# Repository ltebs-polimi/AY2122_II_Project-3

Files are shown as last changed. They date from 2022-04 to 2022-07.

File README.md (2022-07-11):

# Electronic Technologies and Biosensors Lab - Project 3
# Academic Year 2021/2022 - II Semester

## Smart tennis racket able to monitor and classify technical tennis movements

**GOAL**

Classification of the three main tennis shots (forehand, backhand and serve) using a tennis racket equipped with an IMU sensor.

**PROJECT SPECIFICATIONS** 

To pursue this goal we had to: 

*	Acquire and process raw accelerometer and gyroscope data from an IMU sensor.
*   Use a Bluetooth module for real-time communication between the microcontroller and the PC to make the device pluggable on a real racket.
*   Program a classification algorithm for gesture recognition.
*	Provide the end player with a Graphical User Interface to visualize in real-time the type of shots predicted during the match. 
*	Print the custom PCB to reduce instrumentation bulkiness. 
*	Design a 3D printed case that includes the microcontroller and the whole instrumentation. 

**CLINICAL NEEDS**

This project addresses the following clinical needs: 

* Sport performance &#x2192; Recognizing and taking memory of shots is a feature that could simplify the work of tennis trainers, that still take notes manually, to understand if the athletes are developing some fundamentals at expenses of the others. 
In the future, associating the information about the type of shot with the corresponding number of points scored by the player can be useful to understand which are the strengths and the weaknesses of the player and therefore to better target the training. 

* Prevention &#x2192; Epicondylitis is an inflammation of the wrist extensor muscles, at their point of insertion.
It is a consequence of repeated microtraumas over time, typical of those who play tennis.
Some experts state that from 10% to 50% of cases this pathology is due to an incorrect technique of execution of the backhand. 
Therefore, the number of backhand shots made by the tennis player could be a useful information for this purpose.

**HARDWARE** 

On the custom PCB are plugged the following components: 

* PSoC microcontroller &#x2192; 3.3V - 5V of power supply
* 9V battery
* Voltage regulator LM7805 (9V to 5V)
* MPU9250 9-axis IMU sensor &#x2192; 5V of power supply
* Bluetooth module HC-06 &#x2192; 3.3V - 5V power supply 

**DEVICE DESIGN** 

Two 3D printed components, fixed together: 

* Housing of the PCB to be interlocked to the handle of the tennis racket.
* Cap of the case.

**PROBLEMS ENCOUNTERED** 

* The FIFO buffer was not used: the datasheet of the MPU9250 was cryptic, and the implementation very difficult and time consuming. So, we decided to read the data from the IMU continuously by using an interrupt. 

* We could not use the switch button: the problem was in the interrupt used to read the data, that did not allow the button to change its state. We partially fixed this problem by adding a button on the GUI. 

* We could not use the LED on the PCB: the problem was with the PCB trace that linked the LED with the ground plane. We partially solved this problem by adding a LED on the GUI. 

**FUTURE DEVELOPMENTS**

The system we have obtained up to now can be further improved by:
* Combining the intertial measurements with dynamic force sensor measurements (FSR), so as to fully characterize the tennis stroke.
* Calculate meaningful parameters from accelerations through more in-depth data post-processing, useful for biomechanical analysis.
* Visualization of the obtained data plots on the GUI.

-----------------

**Organization of the Github repository**

* *3DPrinting_PCB* &#x2192; design of the 3D prints with Fusion 360
* *Acquisitions* &#x2192; CSV files and Python code to train the classifier
* *Biblio* &#x2192; literature
* *Datasheets* &#x2192; HW components' datasheets
* *PCB* &#x2192; design of the custom PCB with Eagle
* *PSOC_firmware* &#x2192; C code to program PSOC microcontroller and HW components 
* *Python_serial* &#x2192; Python code to acquire, decode, classify and display data on the implemented GUI

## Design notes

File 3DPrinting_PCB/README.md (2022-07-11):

## Electronic Technologies and Biosensors Lab - Project 3
## Academic Year 2021/2022 - II Semester

# CASE DESIGN with FUSION360 

**PREREQUISITES**

The ideal case should be:
-  positioned in a spot on the racket that could not be hit by ball strikes during the game session;
- the least bulky as possible.

To pursue these goals, we thought of print 2 components:
1. a main body for PCB housing &#x2192; to be attached to the handle of the racket, with a geometry compatible with the size of the PCB;
2. an end cap &#x2192; that would allow to open the case to possibly change PCB and its components. 

The main body presents also two holes, one for a switch button to use to activate the device, one for an LED to signal that the device is running. However, these 2 components were not used in the final device. 

We used the Fusion360 to create the design, by following the steps reported below. 

----------------------------------------

**STEPS**

1. MAIN BODY FOR PCB HOUSING

- Create the sketch consisting of a rectangle with sides 50 mm x 60 mm.
- Extrude the sketch from two sides, one to create a hollow parallelepiped of 40 mm height and 3 mm thickness that would fit perfectly to the racket handle, the other to create a parallelepiped of 100 mm height and 2 mm wall thickness that would contain the PCB. 
- Create the 1 mm thick guides on the two side faces of the parallelepiped, starting with 3.6 mm of the middle of the side face. The guides are used to hold the PCB in place.
- Create two holes 0.8 mm and 0.5 mm in diameter at 50 mm and 60 mm from the base for the led and button, respectively.  

2. END CAP

- Divide the body intended to hold the PCB through a dividing plane, at the height of 20 mm from the bottom, thus obtaining two bodies, one upper and one lower.
- Create an intermediate plane between the two outer faces of the upper body.
- Create a sketch on the plane just found.
- Project the whole lower body onto the sketch.
- Establish an interlocking tolerance of 0.5 mm.
- Draw the interlock, by projecting the height of the toggle equal to 7mm.
- Create an extrusion profile of symmetrical type, width equal to 5 mm.
- Create the sketch on the face where the interlock is to be created.
- Project the interlock onto the wall to create the seat of the interlock.
- Set a tolerance offset for the interlock.
- Extrude along the full length of the body thus creating the interlock seat.

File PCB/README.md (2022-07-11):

## Electronic Technologies and Biosensors Lab - Project 3
## Academic Year 2021/2022 - II Semester

# PCB DESIGN with EAGLE 

To develop the PCB with EAGLE, instead of using the symbols and footprints of the various components, we used the Connectors from the *Sparkfun* library.
In this way we used all the available space and we developed a more compact PCB.

We used:
- For the PSOC &#x2192; 22 connectors, carefully spaced in order to follow the component dimensions.
- For the IMU &#x2192; 6 connectors, carefully spaced in order to follow the component dimensions.
- For the HC-06 Bluetooth module &#x2192; 4 connectors in order to follow the component dimensions.
- For the voltage regulator &#x2192; 3 connectors.
- For the battery &#x2192; 2 connectors.
- For the LED and for the button (not used later on) &#x2192; 2 connectors. 
- For the 330&#8486; LED resistance (not used later on) &#x2192; component symbol and footprint.  

After developing the PCB with the standard procedure we soldered the female headers on it and we added the components.

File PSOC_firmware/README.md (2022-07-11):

## Electronic Technologies and Biosensors Lab - Project 3
## Academic Year 2021/2022 - II Semester

# PSoC CODE

This code allows to use a MPU9250 9-axis IMU sensor with a PSoC microcontroller to acquire and transmit accelerometer and gyroscope data using a Bluetooth module. 	

*AnnotationLibrary_lib* is necessary to use the components' APIs and run the code.

--------------------------------------------

**DEFAULT IMU SETTINGS**

- Accelerometer and gyroscope data from the IMU are read when the "Data Ready" internal interrupt is triggered, reporting that "New data is available to be read from Sensors Registers".

- The sample rate is set to 200 Hz by scaling the internal sample rate equal to 1kHz with a sample rate divider equal to 4: SMPLRT = INT_SMPLRT / (1 + SMPLRT_DIV)

- The accelerometer data is expressed in &#177;2 g while the gyroscope data is expressed in &#177;250 dps (degrees per second).

In the *MPU9250.c* file are present all the functions to handle the IMU registers and the FIFO buffer (not used at the end).
The function used to opportunely set the IMU registers in order to follow these settings is *MPU9250_Start()*.

**CODE**

In MPU9250, for each axis of each measurement there are 2 registers containing high and low bytes, for a total of 12 bytes.

We set up the reading settings as follows:

* 1 frame (*data*) containing &#x2192; 12 bytes: contents of the registers related to accelerometer and gyroscope measurements.

* 1 packet (*packet_to_send*) containing &#x2192; (*N_FRAME* * 12 + 2 ) bytes: 
    -	1 HEADER = 0XA0
    -	*N_FRAME* * 12 
    -	1 TAIL = 0XC0

After reading *N_FRAME*, the packet is sent to the PC via HC-06 Bluetooth module (baud rate = 57600 bps).

We set *N_FRAME* = 10, thus creating packets made of 122 bytes.

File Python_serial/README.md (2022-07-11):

## Electronic Technologies and Biosensors Lab - Project 3
## Academic Year 2021/2022 - II Semester

# PYTHON code 

This code allows to:
1.  Collect via Bluetooth the raw data from an MPU9250 9-axis IMU sensor mounted on a smart tennis racket;
2.	Classify the tennis shot made according to the accelerometer & gyroscope measurements obtained;
3.	Display on a GUI the type of shot predicted in real-time.

> IMPORTANT:
* *BT_COM* needs to be specified according to your PC settings.
* *training_dataset.csv* file must be present in the same folder as this code.

--------------------------------------------

**GUI WINDOW & WIDGETS**

In order to create the GUI we have used *Tkinter Python Library* and to make it communicate with the Classification Algorithm we used *Threading Python Library*. 

The GUI contains the following widgets: 

* Timer, which keeps track of the time of the acquisition session.

* LED, which turns green or red depending on the acquisition phase.

* Scoreboard, containing the scores related to the different shots predicted by the Classification Algorithm: *serve*, *forehand* and *backhand*.

* Buttons: 
    * COM &#x2192; to open the serial port (COM) and build the Random Forest Classifier.
    * START &#x2192; to enable the Timer and to activate the 2 threads: *Start_GUI()* and *Start_acquisition()*.
    * STOP &#x2192; to disable the Timer and to block the acquisitions, thus showing the number of shots made up to that moment.
    * RESET &#x2192; to reset Timer and Scoreboard in order to prepare them for another session (to be used after pushing the STOP button).

--------------------------------------------

**DATA COLLECTION**

Once the COM button is pressed, the *BT_COM* port of the Bluetooth module HC-06 is open at baudrate = 57600 bps.
When the START button is pressed, the 2° thread (*Start_acquisition()*) calls the function *Predict_Data_Packet()* which allows to acquire and classify the data from the IMU. 

Each acquisition is done by reading *N_PACKETS* and decoding the corresponding array of data (*data*).
With *N_PACKETS* = 40, the acquisition takes about 4 seconds, which is approximatively equal to the duration of one tennis shot during a match.

Each packet contains 122 bytes: 
-	1 HEADER = 0XA0
-	120 bytes, representing 10 frames of data: each frame contains 12 bytes corresponding to accelerometer and gyroscope data registers, with 2 bytes (high and low bits) for each ACCX, ACCY, ACCZ, GYRX, GYRY, GYRZ reading.
-	1 TAIL = 0XC0

Data decoding is done by creating a *mat_big* matrix with:
-	400 rows &#x2192; *N_FRAME* * *N_PACKETS* = 10*40 
-	6 columns &#x2192; raw data: ACCX, ACCY, ACCZ, GYRX, GYRY, GYRZ (obtained by merging high bytes & low bytes for each measurement and converting the acceleration and gyroscope values to the right FSR (&#177;2g, &#177;250 dps)).

This matrix is then given to the Classification Algorithm that, about every 4 seconds, predicts the type of shot.

--------------------------------------------

**RANDOM FOREST CLASSIFIER**

TRAINING

The *Classifier_Training()* function is run just once when the COM button is pressed. 
The Random Forest Classifier has been trained with 140 acquisitions (*training_dataset.csv*). 
One acquisition is given by the 1°, 2° and 3° quantiles values of the 6 IMU measurements.

For more details about acquistions and choice of the classifier see the *acquisition_protocol.pdf* file in the *Acquisitions* folder.

MAKING PREDICTIONS

In the *Predict_Data_Packet()* function, from the *mat_big* matrix (representing one acquisition), 1° (0.25), 2° (0.5 = median) and 3° (0.75) quantiles of each IMU measurement are extracted and used to guess the shot made with the Random Forest classifier. 
The label *shot* returned by the Classification Algorithm is then used to update the shots' counts in the Scoreboard: 
- shot = 0 &#x2192; Forehand
- shot = 1 &#x2192; Backhand
- shot = 2 &#x2192; Serve
- shot = 3 &#x2192; "no shot"

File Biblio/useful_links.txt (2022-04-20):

https://www.ubitennis.net/2021/01/tennis-in-the-future-an-overview-of-wearables-and-sensors/

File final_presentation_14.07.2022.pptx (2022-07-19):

## SMART TENNIS RACKET FOR TRAINING MONITORING

Electronic Technologies and Biosensors Laboratory
A.A 2021/2022 - presentation 14/07/2022
Politecnico di Milano

Project 3

Tutor: Matteo Rossi
Professor: Pietro Cerveri

Natalia Ginghini
Letizia Mozzorecchia
Aurora Pierantozzi
Adelaide Stucchi

## Goal

Classification of three of the fundamental
tennis shots - forehand, backhand, serve -
by equipping a tennis racket with an
IMU sensor.

## Needs addressed

Sport
Automatic evaluation of athletes’ performances, to understand strenghts and weakenesses, thus better targeting the training.

Clinical
Prevention for Epicondylitis:
10% to 50% of tennis players[1] are at
risk of tennis elbow, mainly due to an
incorrect execution of the backhand.

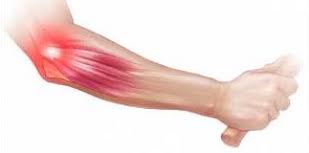
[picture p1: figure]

[1] source: T.K. Robinson PT, DSc, OCS, in Orthopaedic Physical Therapy Secrets (III Edition) (https://www.sciencedirect.com/book/9780323286831/orthopaedic-physical-therapy-secrets), 2017

## Project Specifications

BT COMMUNICATION
PSoC Programmer
between the PSoC and the PC to make the device pluggable on a real racket.

to visualize in real-time the type of shots predicted during the match.
GUI
Python: Tkinter, Threading

3D CASE PRINT
Eagle, Fusion360
to be attached to the racket, in a way that does not interfer during the match.

for real-time gesture recognition of the three
tennis shots.
CLASSIFICATION ALGORITHM
Python: Scikit-learn

1

2

4

3

## Firmware: MPU-9250 settings

Sample rate = 1k Hz / (1 + 4) = 200 Hz

Full scale range
- Accelerometer → ±2 g
- Gyroscope → ±250 dps

Interrupt
Accelerometer & gyroscope registers read when the "Raw Data Ready" internal interrupt is triggered.

## Firmware: Data collection

Registers raw
data reading

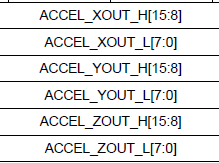
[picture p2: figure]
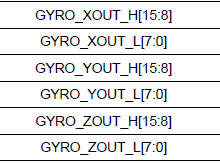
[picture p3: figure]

1 frame
12 bytes

Data
encoding

header
= 0xA0

10 frames
10*12 bytes

tail
= 0xC0

Data
decoding

40 packets

matrix (400,6)
400 rows → N frames * N packets
6 columns → IMU measurements

1 packet
(10*12 + 2) bytes

## PCB: HW components

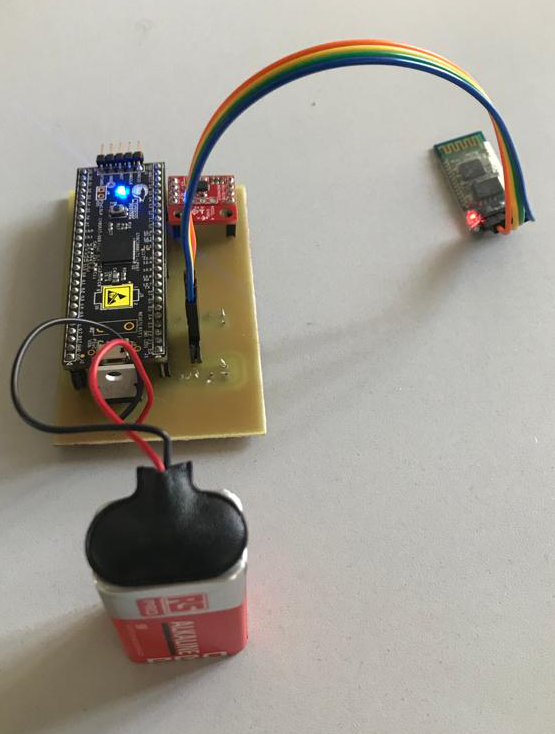
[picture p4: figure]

PSoC 5 microcontroller
5V

Battery
9V

Voltage regulator
9V - 5V

MPU-9250 9-axis IMU
5V

Bluetooth HC-06 module
5V

## Case design: features

Ideal characteristics
- Light & thin
- As small as possible
- Stable during the match
- Protected from the strokes
Location
The case is attached at the bottom of the racket,
so that it does not get hit by the ball during the game.

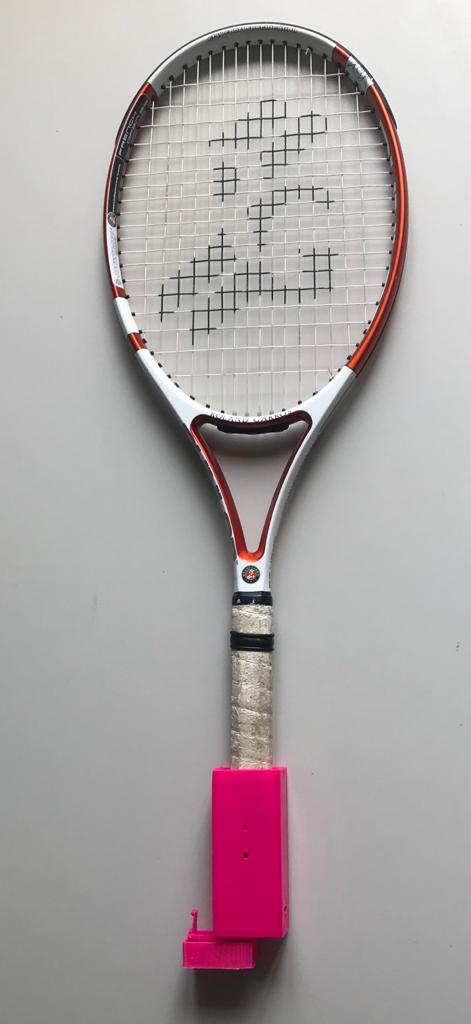
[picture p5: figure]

## Case design: 3D project

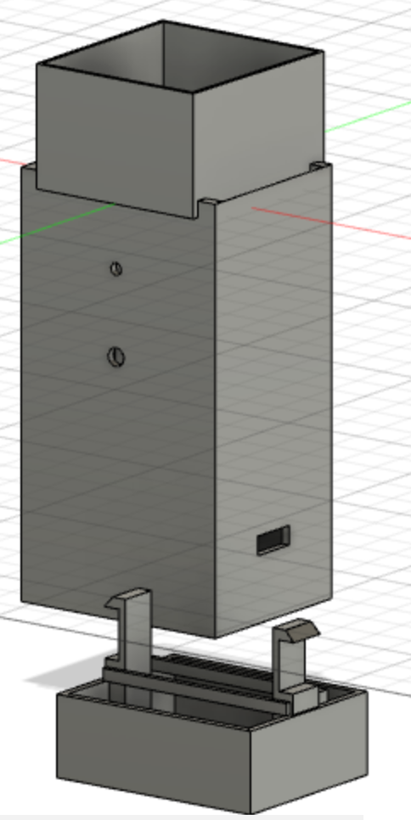
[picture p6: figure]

Attachment to the racket handle

Holes: for led and switch button [2]

BODY 1: PCB HOUSING

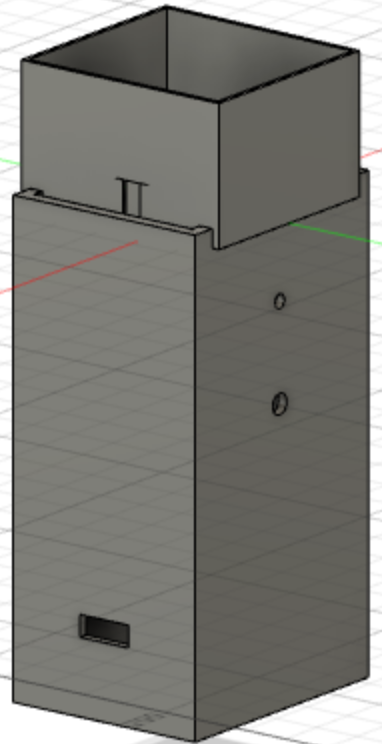
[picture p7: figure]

PCB insertion

Cover, useful if we want to change the PCB or to replace the battery, stabilized through a tape

BODY 2: END CAP

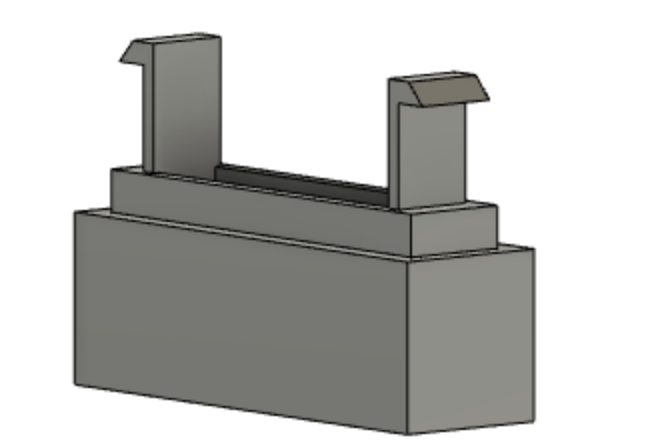
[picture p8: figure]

[2] not present in the final device

## Acquisition protocol

- Right-handed players only.
- Position of the PCB within the case for acquisitions as shown in the picture.
- Total number of subjects → 4
- Duration of each acquisition → 4 sec
- Gestures acquired and related labels:
  - Forehand → label = 0
  - Backhand → label = 1
  - Serve → label = 2
  - No-shot → label = 3

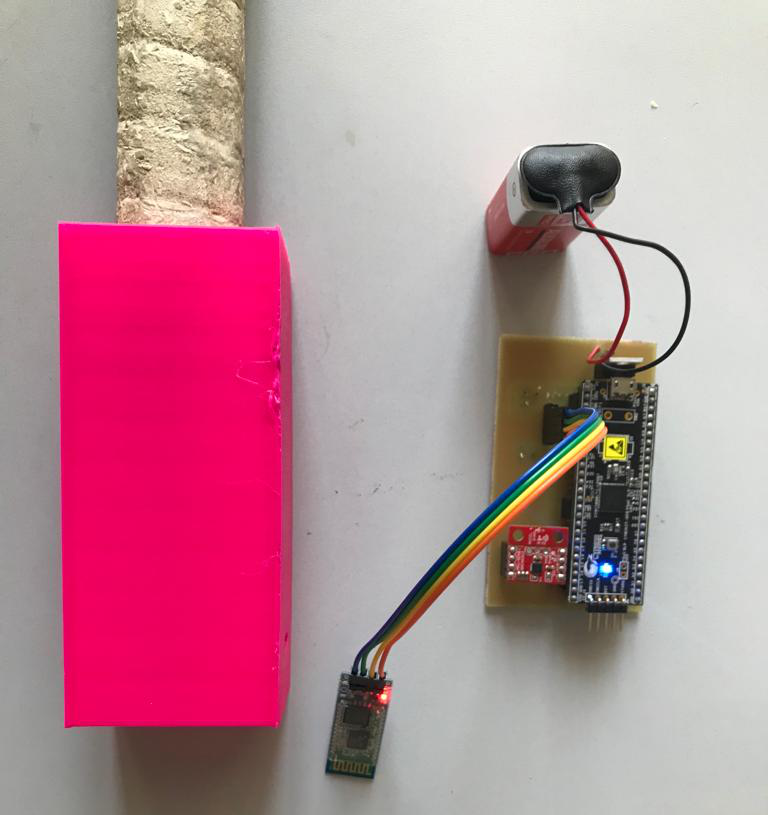
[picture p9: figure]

## Classification

FEATURES ENGINEERING

TRAINING DATASET

TRAINING DATASET

SPLITTING DATASET

SPLITTING DATASET

MULTICLASS CLASSIFIERS

MULTICLASS CLASSIFIERS

- 1 target variable: type of shot → ‘label’.
- 18 explanatory variables: gyroscope and accelerometer quantiles.
- Training: 70% of the entire dataset.
- Test: 30% of the entire dataset.

4 x
4 x
4 x
1 x

forehand: 0
backhand: 1
serve: 2
no shot: 3

x 10
x 10
x 10
x 20

140 acquisition files

training_dataset → (140,19)

Explanatory variables:
- Before
  - IMU measurements: ACCX, ACCY, ACCZ, GYRX, GYRY, GYRZ
  - 1 acquisition file → (400,7)
- After
  - 1° (0.25), 2° (median), 3° (0.75) quantiles of each IMU measurement: ACCX_25, ACCX_50, ACCX_75, … , GYRZ_25, GYRZ_50, GYRZ_75
  - 1 acquisition file → (1,19)

Trained classifiers:
Decision Tree, Logistic Regression, K-Nearest Neighbors, Support Vector Machine, Random Forest.

## Classification algorithm: results

Decision Tree | f1 (train) | f1 (test)
| 0.847222 | 0.857143
| Confusion matrix

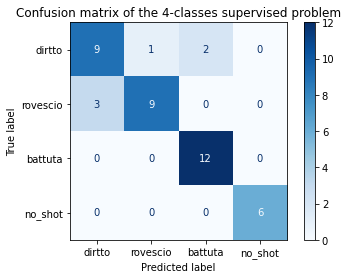
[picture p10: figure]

Log Reg | f1 (train) | f1 (test)
| 0.806818 | 0.809523
| Confusion matrix

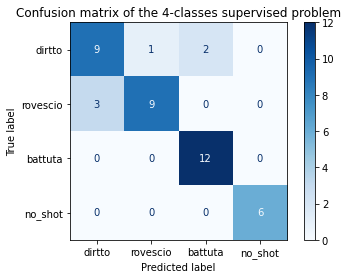
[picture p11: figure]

## Classification algorithm: results

KNN | f1 (train) | f1 (test)
| 0.704861 | 0.761905
| Confusion matrix

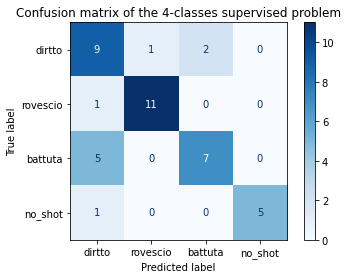
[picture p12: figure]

SVM | f1 (train) | f1 (test)
| 0.938447 | 0.833333
| Confusion matrix

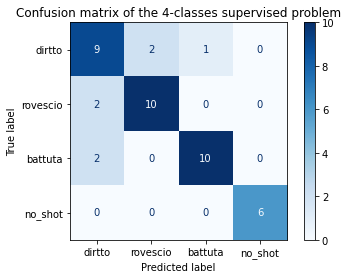
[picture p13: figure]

## Classification algorithm: results

The best classifier is
Random Forest
✔ High F1 score for both training and
test sets.
✔ Similar F1 scores for training test and test set → no overfitting.
✔ Interpretability.

Random Forest | f1 (train) | f1 (test)
| 0.949179 | 0.904761
| Confusion matrix

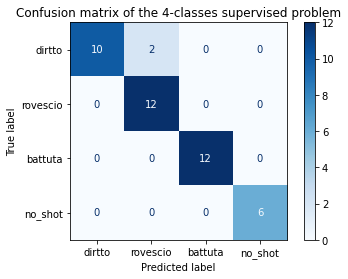
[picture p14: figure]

## GUI

COM
Open the serial port and build the Classifier.

START
Enable Timer and
start the threads.

STOP
Disable Timer and
block acquisitions.

RESET
Prepare Timer and
Scoreboard for the
next session.

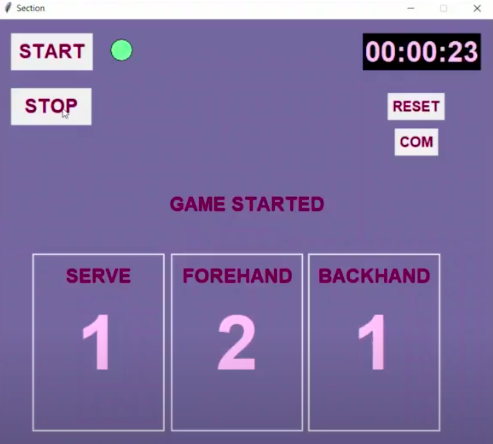
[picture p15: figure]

## Applications of our smart racket

Automatic, real-time classification of 3 tennis shots.

Evaluation and consequent improvement of the athlete’s style of play.

Identification of possible associations between the prevalence of a type of shot with joint pain.

## Problems encountered

- FIFO buffer → not used due to the cryptic MPU-9250 datasheet which made the FIFO implementation difficult and time consuming. We decided, then, to read the data from the IMU continuously by using another internal interrupt (‘Raw Data Ready’).
- Switch button → not used due to the interrupt used to read data registers, that did not allow to read the button state. We partially fixed this problem by adding a button on the GUI.
- LED → not used due to a problem with the PCB trace that linked the LED with the ground plane. We partially solved this problem by adding a LED on the GUI.

## Future developments

- Calculate meaningful parameters from accelerations through more in-depth data post-processing, useful for biomechanical analysis.
- Combining the inertial measurements with dynamic force sensor measurements (e.g. FSR), so as to fully characterize the tennis shot.
- Visualization of the obtained data plots on the GUI.
- Have a larger acquisition dataset in order to obtain more accurate classifications.
- Make the device suitable for left-handers.

## Virtual Demo

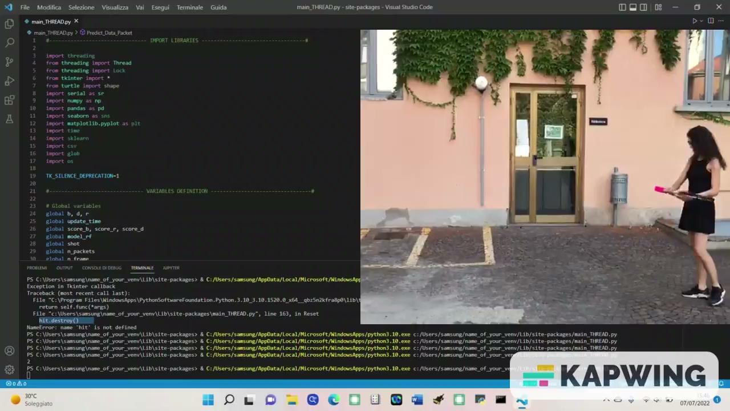
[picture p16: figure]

Thanks for your attention.

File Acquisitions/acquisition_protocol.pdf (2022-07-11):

Electronic Technologies and Biosensors Lab – Project 3 Academic Year 2021/2022 – II Semester

### ACQUISITION PROTOCOL

code used for this purpose: acquisitions_training_classifier.ipynb

Prerequisites

- Right-handed players only.
- Position of the PCB within the case for acquisitions as shown in the picture below (IMU facing the game net in the forehand grip).

Training phase

Number of subjects: 4

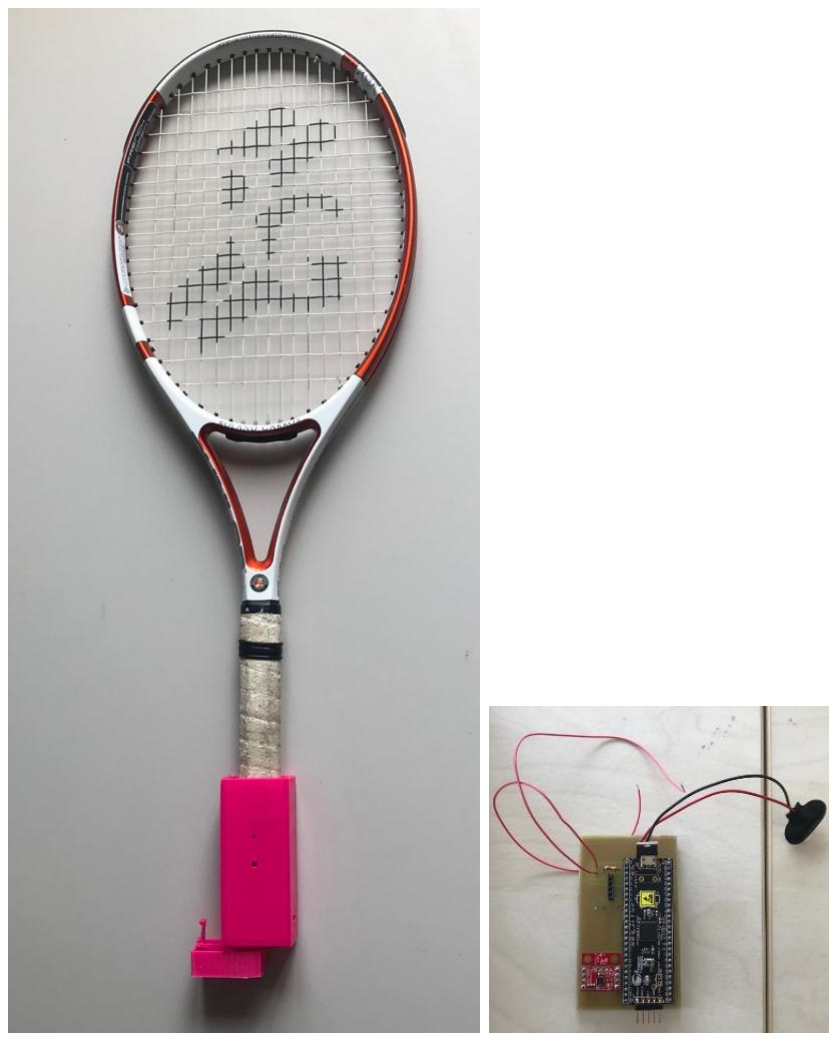
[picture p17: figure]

Duration of each acquisition: about 5 seconds

Gestures acquired and related labels set:

- Forehand : ‘0’
- Backhand: ‘1’
- Serve: ‘2’
- No shot: ‘3’

Number of acquisitions for each shot (‘forehand’, ‘backhand’, ‘serve’) → 10 for each subject. Number of acquisitions for the ‘no shot’ gesture → 20 acquisitions for 1 subject only. Number of acquisition files → 140 (in the “acquisitions_for_TRAINING” folder of the GitHub repository)

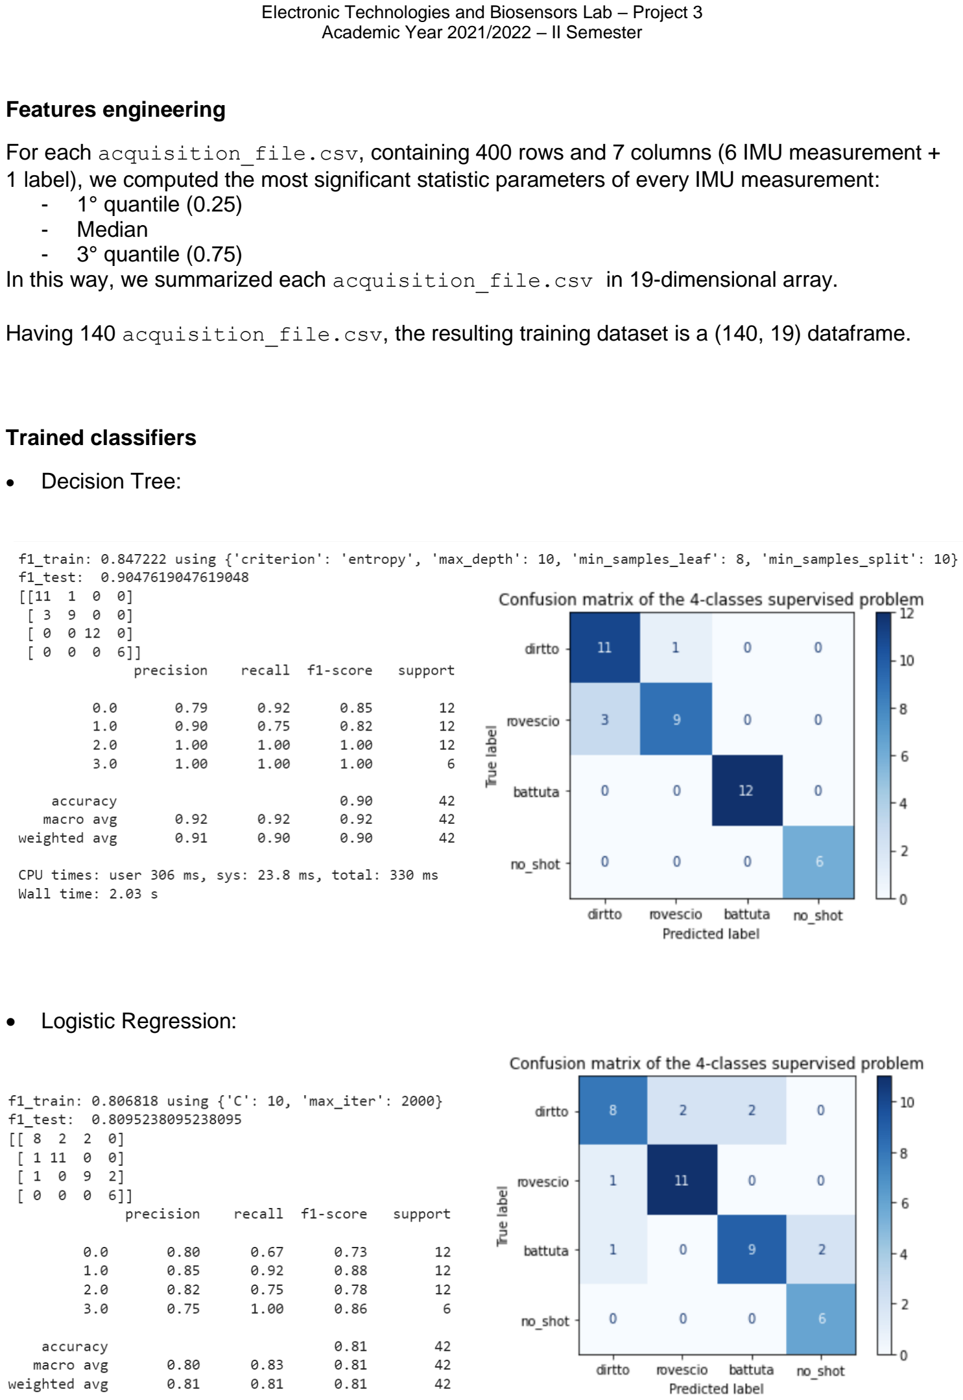
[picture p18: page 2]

Features engineering

For each acquisition_file.csv, containing 400 rows and 7 columns (6 IMU measurement + 1 label), we computed the most significant statistic parameters of every IMU measurement:
- 1° quantile (0.25)
- Median
- 3° quantile (0.75)
In this way, we summarized each acquisition_file.csv in 19-dimensional array.

Having 140 acquisition_file.csv, the resulting training dataset is a (140, 19) dataframe.

Trained classifiers

- Decision Tree:
- Logistic Regression:

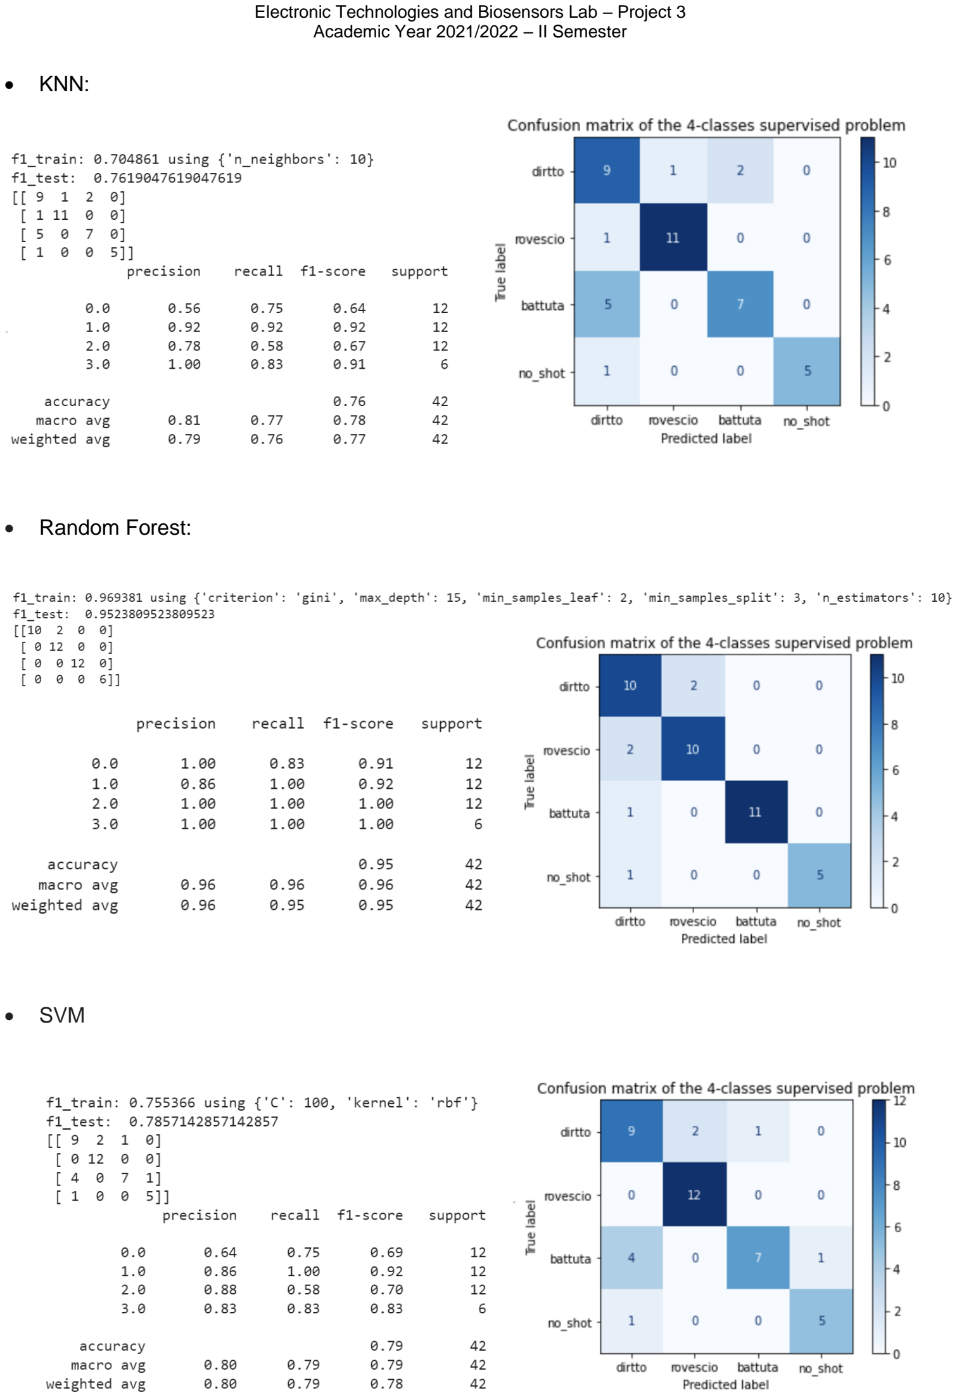
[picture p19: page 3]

- KNN:
- Random Forest:
- SVM

Scaling the data did not lead to significant improvement in the performance of the classifiers, despite improving over fitting in Logistic Regression and KNN; thus, we decided to use the unscaled dataset.

Among the classifiers, we chose Random Forest because of:

✔ High F1 score for both training set and test set.
✔ Similar F1 scores for training sets and test sets, meaning no overfitting problems. ✔ Interpretability of the classifier.

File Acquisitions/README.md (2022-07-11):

## Electronic Technologies and Biosensors Lab - Project 3
## Academic Year 2021/2022 - II Semester

# CLASSIFICATION ALGORITHM FOR GESTURE RECOGNITION

To train and build the classification algorithm able to discriminate the tennis shots by means of accelerometer and gyroscope data, we performed several acquisitions and compared different classifiers.

**ACQUISITION PROTOCOL**

Tennis movements acquired during each acquisition and related labels set: 

- FOREHAND : '0'
- BACKHAND : '1'
- SERVE : '2'
- NO-SHOT : '3'

The acquisitions have been made by following these settings:

* Duration of each acquisition &#x2192; about 4 seconds
* Number of subjects trained &#x2192; 4
* Number of acquisitions for each tennis shot &#x2192; 10 for each subject
* Number of acquisitions ofr the 'no-shot' gesture &#x2192; 20 for 1 subject only
* Number of acquisition files &#x2192; 140 (present in the *acquisitions_for_TRAINING* folder)

**FEATURES ENGINEERING**

For each acquisition CSV file (400,7), we computed: 
- 1° quantile = 0.25
- 2° quantile (median)
- 3° quantile = 0.75

of every IMU measurement, thus summarizing each CSV acquisition file in a 19-dimensional array.

Having 140 acquisition CSV files, the resulting training set is a (140,19) dataframe, converted in the *training_dataset.csv* file.

**TRAINED CLASSIFIERS**

* Decision Tree
* Logistic Regression
* KNN
* Random Forest
* SVM

Among the reported classifiers, we chose Random Forest as it showed the best performances in terms of F1 score, overfitting and interpretability.

> Further details in the *acquisition_protocol.pdf* file.

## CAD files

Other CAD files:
3DPrinting_PCB/CasePCB v2.f3d

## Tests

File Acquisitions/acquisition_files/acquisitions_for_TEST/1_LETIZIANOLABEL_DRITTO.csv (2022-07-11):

ACC_X | ACC_Y | ACC_Z | GYR_X | GYR_Y | GYR_Z
-1.864 | 1.168 | -1.847 | 212.0 | -136.0 | 160.5
-1.864 | 1.168 | -1.847 | 212.0 | -136.0 | 160.5
-1.864 | 1.168 | -1.847 | 212.0 | -136.0 | 160.5
-1.864 | 1.168 | -1.847 | 212.0 | -136.0 | 160.5
-1.864 | 1.168 | -1.847 | 212.0 | -136.0 | 160.5
-1.864 | 1.168 | -1.847 | 212.0 | -136.0 | 160.5
-1.864 | 1.168 | -1.847 | 212.0 | -136.0 | 160.5
-1.864 | 1.168 | -1.847 | 212.0 | -136.0 | 160.5
-1.864 | 1.168 | -1.847 | 212.0 | -136.0 | 160.5
-1.864 | 1.168 | -1.847 | 212.0 | -136.0 | 160.5
-1.864 | 1.168 | -1.847 | 212.0 | -136.0 | 160.5
-1.864 | 1.168 | -1.847 | 212.0 | -136.0 | 160.5
-1.864 | 1.168 | -1.847 | 212.0 | -136.0 | 160.5
-1.864 | 1.168 | -1.847 | 212.0 | -136.0 | 160.5
-1.864 | 1.168 | -1.847 | 212.0 | -136.0 | 160.5
-1.864 | 1.168 | -1.847 | 212.0 | -136.0 | 160.5
-1.864 | 1.168 | -1.847 | 212.0 | -136.0 | 160.5
-1.864 | 1.168 | -1.847 | 212.0 | -136.0 | 160.5
-1.864 | 1.168 | -1.847 | 212.0 | -136.0 | 160.5
-1.864 | 1.168 | -1.847 | 212.0 | -136.0 | 160.5
1.818 | 0.832 | -1.655 | 212.8 | 160.0 | -218.6
1.818 | 0.832 | -1.655 | 212.8 | 160.0 | -218.6
1.818 | 0.832 | -1.655 | 212.8 | 160.0 | -218.6
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

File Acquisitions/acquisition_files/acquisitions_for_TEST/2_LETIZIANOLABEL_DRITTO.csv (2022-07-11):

ACC_X | ACC_Y | ACC_Z | GYR_X | GYR_Y | GYR_Z
1.902 | 1.232 | -1.735 | 167.8 | 244.2 | -230.8
1.902 | 1.232 | -1.735 | 167.8 | 244.2 | -230.8
1.889 | 1.236 | -1.708 | 171.5 | 239.8 | -229.9
1.889 | 1.236 | -1.708 | 171.5 | 239.8 | -229.9
1.889 | 1.236 | -1.708 | 171.5 | 239.8 | -229.9
1.889 | 1.236 | -1.708 | 171.5 | 239.8 | -229.9
1.889 | 1.236 | -1.708 | 171.5 | 239.8 | -229.9
1.889 | 1.236 | -1.708 | 171.5 | 239.8 | -229.9
1.889 | 1.236 | -1.708 | 171.5 | 239.8 | -229.9
1.889 | 1.236 | -1.708 | 171.5 | 239.8 | -229.9
1.902 | 1.232 | -1.735 | 167.8 | 244.2 | -230.8
1.902 | 1.232 | -1.735 | 167.8 | 244.2 | -230.8
1.889 | 1.236 | -1.708 | 171.5 | 239.8 | -229.9
1.889 | 1.236 | -1.708 | 171.5 | 239.8 | -229.9
1.889 | 1.236 | -1.708 | 171.5 | 239.8 | -229.9
1.889 | 1.236 | -1.708 | 171.5 | 239.8 | -229.9
1.889 | 1.236 | -1.708 | 171.5 | 239.8 | -229.9
1.889 | 1.236 | -1.708 | 171.5 | 239.8 | -229.9
1.889 | 1.236 | -1.708 | 171.5 | 239.8 | -229.9
1.889 | 1.236 | -1.708 | 171.5 | 239.8 | -229.9
0.91 | 0.377 | 1.418 | -106.25 | 0.0 | -166.0
0.91 | 0.377 | 1.418 | -106.25 | 0.0 | -166.0
0.91 | 0.377 | 1.418 | -106.25 | 0.0 | -166.0
0.9062 | 0.4238 | 1.426 | -106.5 | 0.0 | -168.5
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

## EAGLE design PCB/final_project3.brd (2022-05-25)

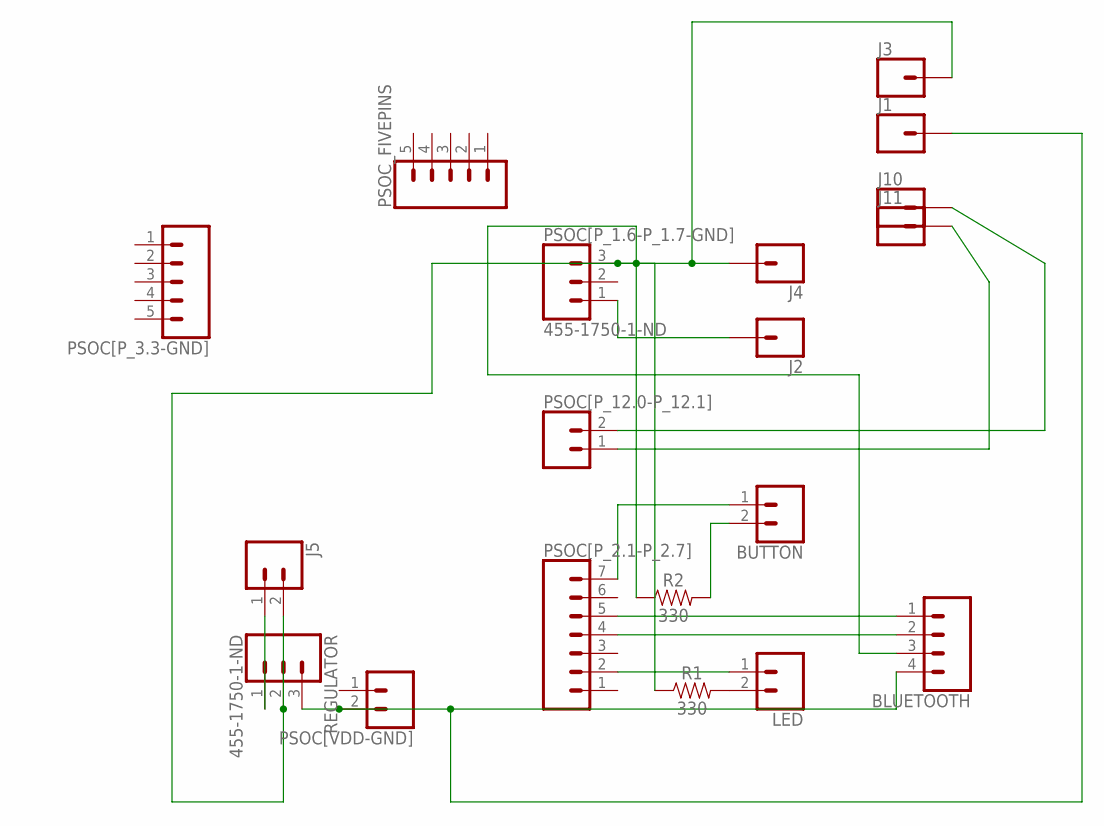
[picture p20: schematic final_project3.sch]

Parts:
BLUETOOTH: CONN_04; 1X04
BUTTON: CONN_02; 1X02
J1, J2, J3, J4, J10, J11: CONN_01; 1X01
J5: CONN_02; 1X02
LED: CONN_02; 1X02
PSOC[P_1.6-P_1.7-GND]: 455-1750-1-ND; 1X03
PSOC[P_2.1-P_2.7]: CONN_07; 1X07
PSOC[P_3.3-GND]: CONN_05; 1X05
PSOC[P_12.0-P_12.1]: CONN_02; 1X02
PSOC[VDD-GND]: CONN_02; 1X02
PSOC_FIVEPINS: CONN_05; 1X05
R1, R2: 330; AXIAL-0.3
REGULATOR: 455-1750-1-ND; 1X03

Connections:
BUTTON: BUTTON.1, PSOC[P_2.1-P_2.7].7
GND3: BLUETOOTH.3, J3.1, J4.1, J5.2, PSOC[P_1.6-P_1.7-GND].3, R1.P$1 (1), R2.P$1 (1), REGULATOR.2
LED: LED.1, PSOC[P_2.1-P_2.7].2
unnamed: J5.1, REGULATOR.1
unnamed: J2.1, PSOC[P_1.6-P_1.7-GND].1
unnamed: J11.1, PSOC[P_12.0-P_12.1].1
unnamed: J10.1, PSOC[P_12.0-P_12.1].2
RX_BT-TX_PSOC: BLUETOOTH.1, PSOC[P_2.1-P_2.7].5
R_BUTTON: BUTTON.2, R2.P$2 (2)
R_LED: LED.2, R1.P$2 (2)
TX_BT-RX_PSOC: BLUETOOTH.2, PSOC[P_2.1-P_2.7].4
VDD: BLUETOOTH.4, J1.1, PSOC[VDD-GND].2, REGULATOR.3

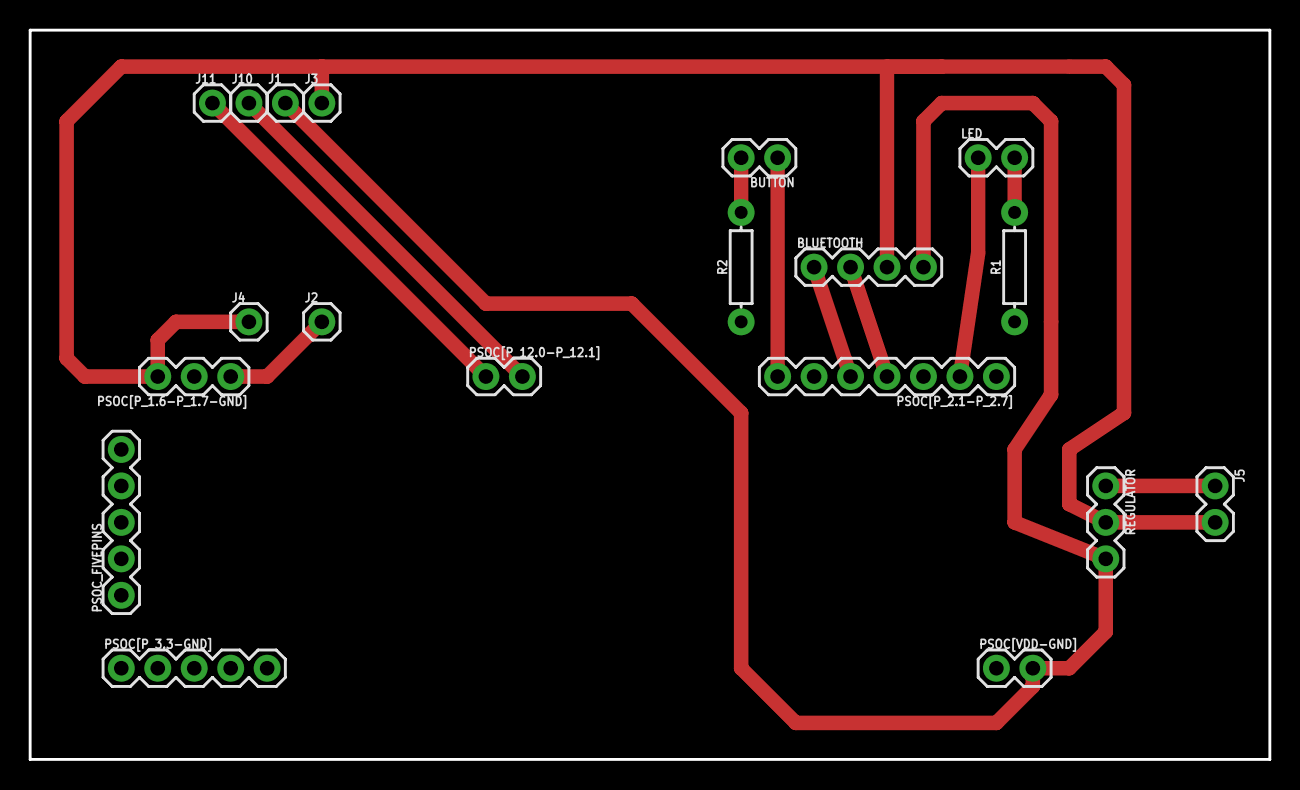
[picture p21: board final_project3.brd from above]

Board: 2 copper layers, 86.4 x 50.8 mm, 19 parts (0 on the bottom side), 12 nets.

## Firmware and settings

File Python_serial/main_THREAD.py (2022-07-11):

#--------------------------------------------- IMPORT LIBRARIES ----------------------------------------------#

import threading 
from threading import Thread
from threading import Lock
from tkinter import *
from turtle import shape
import serial as sr
import numpy as np
import pandas as pd 
import seaborn as sns
import matplotlib.pyplot as plt 
import time
import sklearn
import csv
import glob
import os

TK_SILENCE_DEPRECATION=1

#------------------------------------------ VARIABLES DEFINITION --------------------------------------------#

# Global variables
global b, d, r
global update_time
global score_b, score_r, score_d
global model_rf 
global shot    
global n_packets 
global n_frame 
global send_bytes 
global mat 
global serialPort
global data
global flag_stop
global flag_reset 
global flag_start
global hit


# Variables initialization
hour, minute, second = 0, 0, 0
running = False 
flagb = False 
flagr = False 
flagd = False 
flag_start = False
flag_stop = False
flag_reset = False
BT_COM = "COM19"                                    # Bluethoot HC-06 COM port
n_packets = 40                                      # Number of packets to classify 1 gesture
n_frame = 10                                        # Each packet has n_frame
send_bytes = (12*n_frame)+2                         # Bytes within 1 packet sent by the BT 
mat = np.zeros(shape=(n_frame,6), dtype=np.float16) # Array wtih inside 1 packet of data 




#------------------------------------------ FUNCTIONS DEFINITIONS --------------------------------------------#


##############################################
# Multithreading():
# MULTITHREADING FUNCTION RUNNING IN PARALLEL
#   1. GUI activation
#   2. Data acquisition
##############################################

def Multithreading():
  global t1
  global t2
 
  t1 = Thread(target = Start_GUI)
  t2 = Thread(target = Start_acquisition)
  
  t1.start()
  t2.start()


#############################################################
# Clock():
# FUNCTION ACTIVATING THE CLOCK WHEN START BUTTON IS PRESSED
############################################################# 
  
def Clock():
  global hour, minute, second
  global update_time

  second = second + 1 

  if second == 60:
    minute += 1 
    second = 0 

  if minute == 60:
    hour += 1 
    minute = 0 
            
  string_hour = f'{hour}' if hour > 9 else f'0{hour}'
  string_minute = f'{minute}' if minute > 9 else f'0{minute}'
  string_second = f'{second}' if second > 9 else f'0{second}'
                    
  clock_timer.config(text = string_hour + ":" + string_minute + ":" + string_second)
  update_time = clock_timer.after(1000, Clock)


#############################
# Stop_GUI():
# FUNCTION FREEZING THE GUI
#############################

def Stop_GUI():
  global flag_stop
  global running
  global flagr, flagb, flagd
  global hit
  global b, d, r 

  acquisition.destroy()
  flag_stop = True

  # Stop timer updating
  if running:
    clock_timer.after_cancel(update_time)
    running = False

  # Switch off led
  box_led4 = Canvas(window, bd =0, bg = "#666699", height= 80, width = 80, highlightthickness=0)
  box_led4.grid(row = 20, columns = 7, padx = 135, sticky = "W")
  oval3 = box_led4.create_oval(25,22,55,52, fill = "red")

  # Plot the most frequent hit
  if (b > r and b > d):
    print(b)
    hit = Label(window, text = "The most frequent hit was SERVE", font = ("Orator Std", 15, 'bold'), fg = "#660033", bg = "#666699")   
    hit.grid(row = 40, columns = 8, pady = 50, padx = 160, sticky = "W")

  if (r > b and r > d):
    hit = Label(window, text = "The most frequent hit was BACKHAND", font = ("Orator Std", 15, 'bold'), fg = "#660033", bg = "#666699")   
    hit.grid(row = 40, columns = 8, pady = 50, padx = 160, sticky = "W")

  if (d > r and d > b):
    hit = Label(window, text = "The most frequent hit was FOREHAND", font = ("Orator Std", 15, 'bold'), fg = "#660033", bg = "#666699")   
    hit.grid(row = 40, columns = 8, pady = 50, padx = 160, sticky = "W")

  flagb = False
  flagd = False
  flagr = False
        

#############################
# Reset():
# FUNCTION FOR RESET THE GUI
#############################

def Reset():
  global flag_reset
  global b,d,r
  global flagr, flagb, flagd
  global hour, minute, second
  global b, r, d
  global hit

  hit.destroy()
  acquisition.destroy()

  flag_reset = True

  # Reset scores
  if running:
    clock_timer.after_cancel(update_time)
    score_b.after_cancel(update_scoreboard1)
    score_d.after_cancel(update_scoreboard2)
    score_r.after_cancel(update_scoreboard3)

  flagb = False
  flagd = False
  flagr = False

  # Reset clock time
  hour, minute, second = 0, 0, 0
  b, r, d = 0, 0, 0
  clock_timer.config(text = "00:00:00")
  score_b.config(text="0")
  score_r.config(text="0")
  score_d.config(text="0")

  # Swith OFF led
  box_led3 = Canvas(window, bd =0, bg = "#666699", height= 80, width = 80, highlightthickness=0)
  box_led3.grid(row = 20, columns = 7, padx = 135, sticky = "W" )
  oval3 = box_led3.create_oval(25,22,55,52, fill = "red")


#########################################################
# Scoreboard():
# FUNCTION FOR UPDATE THE SCOREBOARD WITH SHOT PREDICTED
#########################################################

def Scoreboard():
  global b, d, r
  global flagb, flagd, flagr
  global update_scoreboard1, update_scoreboard2, update_scoreboard3
            
  if flagb: 
    b = b + 1
    flagb = False
                
  if flagd:
    d = d + 1
    flagd = False
                
  if flagr:
    r = r + 1
    flagr = False           
                
  score_b.config(text = b)
  update_scoreboard1 = signal_case1.after(4000, Scoreboard)
            
  score_d.config(text = d)
  update_scoreboard2 = signal_case2.after(4000, Scoreboard)
            
  score_r.config(text = r)
  update_scoreboard3 = signal_case3.after(4000, Scoreboard)


#######################################
# System_Initialization():
# FUNCTION FOR INITIALIZING THE SYSTEM: 
#   > Open serial COM port
#   > Training the classifier
#######################################

def System_Initialization(): 
  global serialPort

  # Connection to Bluetooth HC06, baudrate fixed at 57600 
  serialPort = sr.Serial(port = BT_COM, baudrate=57600) 
  
  # Classifier training
  Classifier_Training()


######################################
# Classifier_Training():
# FUNCTION FOR TRAINING THE CLASSIFIER 
######################################

def Classifier_Training():
  global model_rf
  
  # Import data collected
  df_all = pd.read_csv('training_dataset.csv') #(140,19)

  # Cleaning the dataset, removing infinte and NaN values
  df_all.replace([np.inf, -np.inf], np.nan, inplace=True)
  df_all.dropna(inplace=True)
  df_all = df_all.reset_index(drop=True) #(140,19)

  # Target variable = type of gesture {0,1,2,3}
  y = df_all["label"]

  # New statistics explanatory variables: 1° quantile, median, 3° quantile for each of the 6 IMU measurements 
  X = df_all.drop("label", axis=1) 

  # Split in training & test dataset
  from sklearn.model_selection import train_test_split
  X_train, X_test, y_train, y_test = train_test_split(X, y, 
                                                      test_size = 0.30,   
                                                      stratify = y,        
                                                      random_state = 123) 

  # Model fit with Random Forest 
  from sklearn.ensemble import RandomForestClassifier

  # Best hyperparameters according to GridSearchCV
  model_rf = RandomForestClassifier(n_estimators=10, 
                                    criterion='gini', 
                                    max_depth=15, 
                                    min_samples_split=3, 
                                    min_samples_leaf=2)
  # Model fit
  model_rf.fit(X_train, y_train)


#####################################################
# Start_GUI():
# FUNCTION MODIFYING GUI WHEN START BUTTON IS PRESSED:  
#   > Activate clock
#   > Display "Game started"
#   > Switch on LED
#####################################################

def Start_GUI():
  global running
  global acquisition

  if not running:
    Clock()
    running = True 
  
  box_led2 = Canvas(window, bd = 0, bg = "#666699", height = 80, width = 80, highlightthickness= 0)
  box_led2.grid(row = 20, columns = 7, padx = 135, sticky = "W")
  oval2 = box_led2.create_oval(25,22,55,52, fill = "light green")
           
  acquisition = Label(window, text = "GAME STARTED", font = ("Orator Std", 20, 'bold'), fg = "#660033", bg = "#666699")
  acquisition.grid(row = 40, columns = 8, pady = 50, padx = 240, sticky = "w")


#########################################
# Predict_Data_Packet():
# FUNCTION FOR DATA READING & PREDICTION   
#   > Reading 1 packet of data via serial
#   > Data prediction with RF classifier
#   > Update of the GUI
#########################################

def Predict_Data_Packet(): 
  global flagb, flagr, flagd
  global mat_big

  for packets in range(0,n_packets): 

    # Reading 1 packet (with n_frame inside) 
    data = serialPort.read(send_bytes) 

    # Check for header and tail 
    if ((data[0] == 0XA0) and (data[0+(send_bytes-1)] == 0XC0)):

      # For each frame of the packet create the matrix containing the 6 registers' values
      for r in range(0,n_frame): 
        c=0
        for i in range (1,12,2): 
            col = np.float16((data[i+12*(r)]<<8) + data[(i+1)+12*(r)])
            mat[r,c] = col
            c+=1 

      # FSR conversion
      for k in range(0,3):  
        mat[:,k] = mat[:,k]*(4/65535)-2     # +-2 g for accelerometer
      for j in range(3,6): 
        mat[:,j] = mat[:,j]*(500/65535)-250 # +-250 dps for gyroscope

    if (packets == 0):     
      mat_big = mat

    else:
      mat_big = np.concatenate((mat_big,mat), axis=0)

  # Dataframe of the single acquisition (400x6) to be classified
  df = pd.DataFrame(mat_big, 
                    columns = ["ACC_X", "ACC_Y", "ACC_Z", "GYR_X", "GYR_Y", "GYR_Z"])

  # Cleaning the dataframe 
  df.replace([np.inf, -np.inf], np.nan, inplace=True) # Replace infinite updated data with NaN
  df.dropna(inplace=True)                             # Drop rows with NaN
  df = df.reset_index(drop=True)                      # Reset indexes

  # Creating new explanatory variables: 1°, 2°, 3° quantiles
  X_quantiles = np.empty((1,18))

  for i in range(18):
    if (i==0) or (i%3 == 0): Q = 0.25
    if (i==1) or (i==4) or (i==7) or (i==10) or (i==13) or (i==16): Q = 0.5
    if (i==2) or (i==5) or (i==8) or (i==11) or (i==14) or (i==17): Q = 0.75

    if (i<=2):  
      X_quantiles[0,i] = np.quantile(df['ACC_X'],Q)
    if (i>2) and (i<=5):  
      X_quantiles[0,i] = np.quantile(df['ACC_Y'],Q)
    if (i>5) and (i<=8):  
      X_quantiles[0,i] = np.quantile(df['ACC_Z'],Q)
    if (i>8) and (i<=11): 
      X_quantiles[0,i] = np.quantile(df['GYR_X'],Q)
    if (i>11) and (i<=14):  
      X_quantiles[0,i] = np.quantile(df['GYR_Y'],Q)
    if (i>14) and (i<=17):  
      X_quantiles[0,i] = np.quantile(df['GYR_Z'],Q)
  

  # Dataframe of the single acquisition (1x18) to be classified
  df_to_test = pd.DataFrame(X_quantiles, columns = ['ACCX_25', 'ACCX_50','ACCX_75',
                                                    'ACCY_25', 'ACCY_50','ACCY_75',
                                                    'ACCZ_25', 'ACCZ_50','ACCZ_75',
                                                    'GYRX_25', 'GYRX_50','GYRX_75',
                                                    'GYRY_25', 'GYRY_50','GYRY_75',
                                                    'GYRZ_25', 'GYRZ_50','GYRZ_75'])

  # Prediction for the single acquisition made
  shot = model_rf.predict(df_to_test)

  # Update GUI scoreboard
  if (shot == 0): flagd = True
  if (shot == 1): flagr = True
  if (shot == 2): flagb = True
  
  Scoreboard() 


##############################################
# Start_acquisition():
# FUNCTION ENABLING DATA READING & PREDICTION
##############################################

def Start_acquisition():

  flag_start = True

  while(flag_start):
    Predict_Data_Packet()

    if (flag_stop):
      flag_start = False
      break

    if (flag_reset):
      flag_start = False
      break


#----------------------------------------------- GUI CREATION ------------------------------------------------#

# Window
window = Tk()
window.geometry("700x600")
window.title("Section")
window.resizable(False, False)
window.config(background = "#666699")

# Timer
clock_timer = Label(window, text = "00:00:00", bg = "black", fg = "#ffccff", font = ("Helvetica", 30, 'bold'))
clock_timer.grid(row = 20, columns = 400, padx = 500, sticky = "NE", pady = 20)

# Led
box_led = Canvas(window, bd = 0, bg = "#666699", height = 80, width = 80, highlightthickness=0)
box_led.grid(row = 20, columns = 7, padx = 135, sticky = "W")
oval = box_led.create_oval(25,22,55,52, fill="red")

# "Game started" label
acquisition = Label(window, text = "GAME STARTED", font = ("Orator Std", 20, 'bold'), fg = "#666699", bg = "#666699" )
acquisition.grid(row = 40, columns = 8, pady = 50, padx = 160, sticky = "W")

# Buttons
start = Button(window, text = "START", command = Multithreading,  bd= 0, font = ("Orator Std", 20, 'bold'), fg = "#660033")
start.grid(row = 20, column =0, padx = 20, pady = 20, sticky = "NW")

stop = Button(window, text = " STOP ", command = Stop_GUI, bd = 0, font = ("Orator Std", 20, 'bold'), fg = "#660033")
stop.grid(row = 21, column = 0, padx = 20, pady = 5, sticky = "NW")

resets = Button(window, text = "RESET", command = Reset, bd = 0, font = ("Orator Std", 15, 'bold'), fg = "#660033")
resets.grid(row = 21, columns = 400)

com = Button(window, text = "COM", command = System_Initialization, bd = 0, font = ("Orator Std", 15, 'bold'), fg = "#660033")
com.grid(row = 22, columns = 400, padx = 560, pady = 0, sticky = "NW")

# "Serve" scores
signal_case1 = Canvas(window, bg = "#666699", height = 230, width = 186)
signal_case1.grid(row = 42, columns = 7, sticky = "W", padx = 50)
serve = signal_case1.create_text(93,32, text = "SERVE", fill = "#660033", font = ('Orator Std', 20, 'bold'))
b = 0
score_b = Label(signal_case1, bg = "#666699", text = b, fg = "#ffccff", font = ('Helvetica', 80, 'bold'))
score_b.grid(row=42, columns = 7, padx =60, pady = 60)

# "Forehand" scores
signal_case2 = Canvas(window, bd = 0, bg = "#666699", height = 230, width = 186)
signal_case2.grid(row = 42, columns = 8, sticky = "W", padx = 245)
forehand = signal_case2.create_text(93,32, text = "FOREHAND", fill = "#660033", font = ('Orator Std', 20, 'bold'))
d = 0
score_d = Label(signal_case2, bg = "#666699", text = d, fg = "#ffccff", font = ('Helvetica', 80, 'bold'))
score_d.grid(row = 42, columns = 8, padx = 60, pady = 60)

# "Backhand" scores
signal_case3 = Canvas(window, bd = 0, bg = "#666699", height = 230, width = 186)
signal_case3.grid(row = 42, columns = 9, sticky = "W", padx = 438)
backhand = signal_case3.create_text(93,32, text = "BACKHAND", fill = "#660033", font = ('Orator Std', 20, 'bold'))
r = 0
score_r = Label(signal_case3, text = r, bg = "#666699", fg = "#ffccff", font = ('Helvetica', 80, 'bold'))
score_r.grid(row = 42, columns = 9, padx = 60, pady = 60)

window.mainloop()

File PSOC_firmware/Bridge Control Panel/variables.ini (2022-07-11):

[VARIABLES_SETTINGS]
PACKET=1
SCROLL=0
AXIS_X_TYPE=0
AUTO_RANGE_OF_AXIS_Y=1
AXIS_Y_MIN=0
AXIS_Y_MAX=500
SHOW_FLAGS=0
AMPLITUDE=10
THICKNESS=1
VARIABLES=32
Var1.Number=1
Var1.Active=True
Var1.VariableName=accX
Var1.Type=int
Var1.Sign=True
Var1.Scale=6.1E-05
Var1.Offset=0
Var1.Color=Black
Var2.Number=2
Var2.Active=True
Var2.VariableName=accY
Var2.Type=int
Var2.Sign=True
Var2.Scale=6.1E-05
Var2.Offset=0
Var2.Color=Blue
Var3.Number=3
Var3.Active=True
Var3.VariableName=accZ
Var3.Type=int
Var3.Sign=True
Var3.Scale=6.1E-05
Var3.Offset=0
Var3.Color=BlueViolet
Var4.Number=4
Var4.Active=True
Var4.VariableName=gyroX
Var4.Type=int
Var4.Sign=True
Var4.Scale=1
Var4.Offset=0
Var4.Color=Red
Var5.Number=5
Var5.Active=True
Var5.VariableName=gyroY
Var5.Type=int
Var5.Sign=True
Var5.Scale=1
Var5.Offset=0
Var5.Color=Orange
Var6.Number=6
Var6.Active=True
Var6.VariableName=gyroZ
Var6.Type=int
Var6.Sign=True
Var6.Scale=1
Var6.Offset=0
Var6.Color=LawnGreen
Var7.Number=7
Var7.Active=False
Var7.VariableName=Key7
Var7.Type=byte
Var7.Sign=False
Var7.Scale=1
Var7.Offset=0
Var7.Color=Magenta
Var8.Number=8
Var8.Active=False
Var8.VariableName=Var8
Var8.Type=byte
Var8.Sign=False
Var8.Scale=1
Var8.Offset=0
Var8.Color=Olive
Var9.Number=9
Var9.Active=False
Var9.VariableName=Var9
Var9.Type=byte
Var9.Sign=False
Var9.Scale=1
Var9.Offset=0
Var9.Color=MidnightBlue
Var10.Number=10
Var10.Active=False
Var10.VariableName=Var10
Var10.Type=byte
Var10.Sign=False
Var10.Scale=1
Var10.Offset=0
Var10.Color=Orange
Var11.Number=11
Var11.Active=False
Var11.VariableName=Var11
Var11.Type=byte
Var11.Sign=False
Var11.Scale=1
Var11.Offset=0
Var11.Color=SeaGreen
Var12.Number=12
Var12.Active=False
Var12.VariableName=Var12
Var12.Type=byte
Var12.Sign=False
Var12.Scale=1
Var12.Offset=0
Var12.Color=Maroon
Var13.Number=13
Var13.Active=False
Var13.VariableName=Var13
Var13.Type=byte
Var13.Sign=False
Var13.Scale=1
Var13.Offset=0
Var13.Color=OrangeRed
Var14.Number=14
Var14.Active=False
Var14.VariableName=Var14
Var14.Type=byte
Var14.Sign=False
Var14.Scale=1
Var14.Offset=0
Var14.Color=Purple
Var15.Number=15
Var15.Active=False
Var15.VariableName=Var15
Var15.Type=byte
Var15.Sign=False
Var15.Scale=1
Var15.Offset=0
Var15.Color=SaddleBrown
Var16.Number=16
Var16.Active=False
Var16.VariableName=Var16
Var16.Type=byte
Var16.Sign=False
Var16.Scale=1
Var16.Offset=0
Var16.Color=Gray
Var17.Number=17
Var17.Active=False
Var17.VariableName=Var17
Var17.Type=byte
Var17.Sign=False
Var17.Scale=1
Var17.Offset=0
Var17.Color=Black
Var18.Number=18
Var18.Active=False
Var18.VariableName=Var18
Var18.Type=byte
Var18.Sign=False
Var18.Scale=1
Var18.Offset=0
Var18.Color=Blue
Var19.Number=19
Var19.Active=False
Var19.VariableName=Var19
Var19.Type=byte
Var19.Sign=False
Var19.Scale=1
Var19.Offset=0
Var19.Color=Lime
Var20.Number=20
Var20.Active=False
Var20.VariableName=Var20
Var20.Type=byte
Var20.Sign=False
Var20.Scale=1
Var20.Offset=0
Var20.Color=Red
Var21.Number=21
Var21.Active=False
Var21.VariableName=Var21
Var21.Type=byte
Var21.Sign=False
Var21.Scale=1
Var21.Offset=0
Var21.Color=BlueViolet
Var22.Number=22
Var22.Active=False
Var22.VariableName=Var22
Var22.Type=byte
Var22.Sign=False
Var22.Scale=1
Var22.Offset=0
Var22.Color=LawnGreen
Var23.Number=23
Var23.Active=False
Var23.VariableName=Var23
Var23.Type=byte
Var23.Sign=False
Var23.Scale=1
Var23.Offset=0
Var23.Color=Magenta
Var24.Number=24
Var24.Active=False
Var24.VariableName=Var24
Var24.Type=byte
Var24.Sign=False
Var24.Scale=1
Var24.Offset=0
Var24.Color=Olive
Var25.Number=25
Var25.Active=False
Var25.VariableName=Var25
Var25.Type=byte
Var25.Sign=False
Var25.Scale=1
Var25.Offset=0
Var25.Color=MidnightBlue
Var26.Number=26
Var26.Active=False
Var26.VariableName=Var26
Var26.Type=byte
Var26.Sign=False
Var26.Scale=1
Var26.Offset=0
Var26.Color=Orange
Var27.Number=27
Var27.Active=False
Var27.VariableName=Var27
Var27.Type=byte
Var27.Sign=False
Var27.Scale=1
Var27.Offset=0
Var27.Color=SeaGreen
Var28.Number=28
Var28.Active=False
Var28.VariableName=Var28
Var28.Type=byte
Var28.Sign=False
Var28.Scale=1
Var28.Offset=0
Var28.Color=Maroon
Var29.Number=29
Var29.Active=False
Var29.VariableName=Var29
Var29.Type=byte
Var29.Sign=False
Var29.Scale=1
Var29.Offset=0
Var29.Color=OrangeRed
Var30.Number=30
Var30.Active=False
Var30.VariableName=Var30
Var30.Type=byte
Var30.Sign=False
Var30.Scale=1
Var30.Offset=0
Var30.Color=Purple
Var31.Number=31
Var31.Active=False
Var31.VariableName=Var31
Var31.Type=byte
Var31.Sign=False
Var31.Scale=1
Var31.Offset=0
Var31.Color=SaddleBrown
Var32.Number=32
Var32.Active=False
Var32.VariableName=Var32
Var32.Type=byte
Var32.Sign=False
Var32.Scale=1
Var32.Offset=0
Var32.Color=Gray
[FLAGS_SETTINGS]
FLAGS=16
Flag1.Number=1
Flag1.Active=False
Flag1.VariableName=accX
Flag1.FlagName=gf0
Flag1.BitMask=00000000
Flag1.Inversion=False
Flag1.Visible=False
Flag1.Position=0
Flag1.Color=Blue
Flag2.Number=2
Flag2.Active=False
Flag2.VariableName=accX
Flag2.FlagName=gf1
Flag2.BitMask=00000000
Flag2.Inversion=False
Flag2.Visible=False
Flag2.Position=0
Flag2.Color=BlueViolet
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

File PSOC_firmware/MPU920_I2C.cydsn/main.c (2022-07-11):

/* ========================================
 * Project 3 
 * FIRMWARE CODE - MPU9250 IMU SENSOR 
 * 
 * ========================================
*/


// Include required header files
#include "project.h"
#include "MPU9250.h"
#include "stdio.h"

// Variables declaration
#define N_FRAME 10 
int flag_data_ready = 0; 
int i;
int k;
uint8_t packet_to_send[(N_FRAME*12)+2]; // 1 packet of data to send contains: N_FRAMES of data + header and tail
uint8_t data[12];                       // 1 frame of data read from the IMU


CY_ISR_PROTO(MPU9250_DR_ISR);

int main(void)
{
    // Enable global interrupt
    CyGlobalIntEnable; 
    
    // Start UART & BT components
    UART_BT_Start();
    
    // Start I2C component
    I2C_MPU9250_Master_Start();
    
    CyDelay(1000);
    
    uint8_t connection = 0;                 // variable to store connection status
    packet_to_send[(N_FRAME*12)+1] = 0xC0;  // tail
    packet_to_send[0] = 0xA0;               // header
    
    // Wait until MPU9250 is connected
    do {
        connection = MPU9250_IsConnected();
    } while (connection == 0);
    
    // Start the MPU9250
    MPU9250_Start(); 
    MPU9250_ISR_StartEx(MPU9250_DR_ISR);
    
    for(;;)
    {
        // Check for switch button
        
    }
}


CY_ISR(MPU9250_DR_ISR) {  
    
    PIN_LED_Write(1); // Always on for the user 
    
    // Load data on the packet to be sent
    for (i=0; i<N_FRAME; i++) {
        
        // Read data 
        MPU9250_ReadAccGyroRaw(&data[0]);
        
        for (k = (1+i*12); (k < (13+(i*12))); k++) {            
            packet_to_send[k] = data[(k-1)-(i*12)];      
        }
    }
            
    if (i == (N_FRAME)) {
        
        // Send packet over BT once having put inside the packet N_FRAME of data 
        UART_BT_PutArray(packet_to_send,(N_FRAME*12)+2); 
        
        // Refresh the packet
        k = 0;
        i = 0; 
    }
    
    MPU9250_ReadInterruptStatus();
    
}

/* [] END OF FILE */

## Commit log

2022-05-20 Addind schematic
    [final_project3.sch]
2022-05-20 Adding schematic
    [final_project3.sch]
2022-05-20 Schematic modification, board
    [final_project3.brd]
2022-05-25 Firmware updated
    [FinalProject.sdf]
2022-05-25 specifiche di progetto - prima bozza
2022-05-25 Created folder for 3D printer files
    [idea1 v1.f3d, idea2 v1.f3d]
2022-06-10 removing old files
    [FinalProject.sdf, idea1 v1.f3d, idea2 v1.f3d]
2022-06-15 Changed pin BT according to PCB
2022-06-23 first acquisitions data & training of the classifier
    [BATTUTA10_Adelaide.csv, BATTUTA10_Aurora.csv, BATTUTA1_Adelaide.csv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]
2022-06-29 Upload of 29.06 new acquisitions' data
    [10LETIZIA_NOSHOT.csv, 11LETIZIA_NOSHOT.csv, 12LETIZIA_NOSHOT.csv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]
2022-06-29 Removed old ipynb files
    [BATTUTA10_Adelaide.csv, BATTUTA10_Aurora.csv, BATTUTA1_Adelaide.csv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]
2022-07-01 Upload README file for PCB EAGLE design
2022-07-01 Upload acquisitions files and ipynb code for training classifiers
    [10LETIZIA_NOSHOT.csv, 11LETIZIA_NOSHOT.csv, 12LETIZIA_NOSHOT.csv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]
2022-07-01 Upload final training dataset with 56000 rows
    [training_dataset.csv]
2022-07-01 Changed location to some folders
    [10LETIZIA_NOSHOT.csv, 11LETIZIA_NOSHOT.csv, 12LETIZIA_NOSHOT.csv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]
2022-07-04 Upload README Fusion360
    [CasePCB v2.f3d]
2022-07-04 Upload new training dataset with new explanatory variables
    [training_dataset_stat.csv]
2022-07-05 Uplaod training set with new acquisitions
    [training_dataset_stat_NEW.csv]
2022-07-06 Upload new acquisition files
    [10LETIZIA_NOSHOT.csv, 11LETIZIA_NOSHOT.csv, 12LETIZIA_NOSHOT.csv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]
2022-07-06 Upload new training dataset
    [training_dataset_stat_NEW.csv]
2022-07-06 Renamed training dataset
    [training_dataset.csv]
2022-07-06 Removed old .py files
    [training_dataset.csv]
2022-07-06 Renamed folders
    [10LETIZIA_NOSHOT.csv, 11LETIZIA_NOSHOT.csv, 12LETIZIA_NOSHOT.csv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]

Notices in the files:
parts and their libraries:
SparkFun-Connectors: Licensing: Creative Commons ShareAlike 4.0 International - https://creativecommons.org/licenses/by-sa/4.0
